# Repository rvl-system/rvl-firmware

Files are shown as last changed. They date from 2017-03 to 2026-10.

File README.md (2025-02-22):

# RVL Firmware

Source code for my RVL system, meant to be run on [RVL Controller Boards](https://github.com/rvl-system/rvl-controller-board). Written using [PlatformIO](http://platformio.org/).

This project is still under heavy development, documentation coming soon once things have settled!

In the mean time, check out this tech demo video of the hardware (as of July 2018).

<a href="https://www.youtube.com/watch?v=nYG6840g4mw" target="_blank">
  Video of a tech demonstration of RVL version 3
</a>

And a photo of the system on my bike at Burning Man 2017:

Photo of RVL on a bike at Burning Man 2017

And finally a video of an art piece I designed the lighting for at Burning Man 2019

<a href="https://www.youtube.com/watch?v=HZNM6n1g5n8" target="_blank">
  Video of a tech demonstration of RVL version 3
</a>

## Notes

The ESP32 sometimes has trouble with Linksys brand routers. If you find that controllers work for a while, then disconnect and never reconnect, try a different router.

# License

All schematics, layouts, software, and other documentation for raver-lights is released under the General Public License.

Copyright (c) Bryan Hughes <bryan@nebri.us>

RVL is free software: you can redistribute it and/or modify
it under the terms of the GNU General Public License as published by
the Free Software Foundation, either version 3 of the License, or
(at your option) any later version.

RVL is distributed in the hope that it will be useful,
but WITHOUT ANY WARRANTY; without even the implied warranty of
MERCHANTABILITY or FITNESS FOR A PARTICULAR PURPOSE.  See the
GNU General Public License for more details.

You should have received a copy of the GNU General Public License
along with RVL.  If not, see <http://www.gnu.org/licenses/>.

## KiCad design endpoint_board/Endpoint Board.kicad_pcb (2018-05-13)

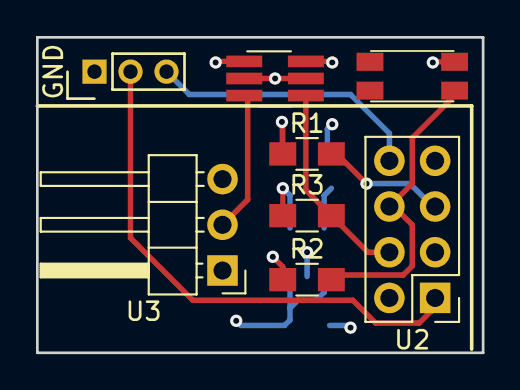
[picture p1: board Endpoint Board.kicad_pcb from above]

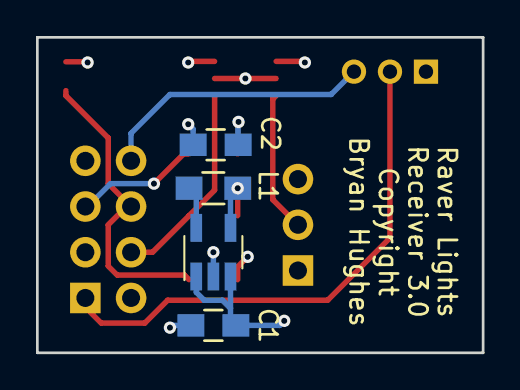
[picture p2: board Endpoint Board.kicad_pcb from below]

Board: 4 copper layers, 24.8 x 17.5 mm, 12 parts (4 on the bottom side), 10 nets.

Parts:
C1: 4.7uF; C_0805_HandSoldering
C2: 10uF; C_0805_HandSoldering
L1: 2.2uH; R_0805_HandSoldering
P4: SERIAL; Pin_Header_Straight_1x03_Pitch2.00mm
R1, R3: 10k; R_0805_HandSoldering
R2: 1k; R_0805_HandSoldering
SW1: SW_DPST; KMR641NG
U1: LM3671; SOT-23-5_HandSoldering
U2: ESP-01; Pin_Header_Straight_2x04_Pitch2.54mm
U3: NeoPixel; Pin_Header_Angled_1x03_Pitch2.54mm
U4: SN74LVC1T45; TSOT-23-6_HandSoldering

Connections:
+5V: C1.1, U1.1, U1.3, U3.3, U4.1
GND: C1.2, C2.2, P4.1, SW1.2, U1.2, U2.2, U3.1, U4.2, U4.5
unnamed: L1.1, U1.5
unnamed: P4.2, U2.1
unnamed: P4.3, U2.8
unnamed: R1.2, U2.5
unnamed: R2.2, SW1.1, U2.6
unnamed: R3.2, U2.4, U4.4
unnamed: U3.2, U4.3
VCC: C2.1, L1.2, R1.1, R2.1, R3.1, U1.4, U2.3, U2.7, U4.6

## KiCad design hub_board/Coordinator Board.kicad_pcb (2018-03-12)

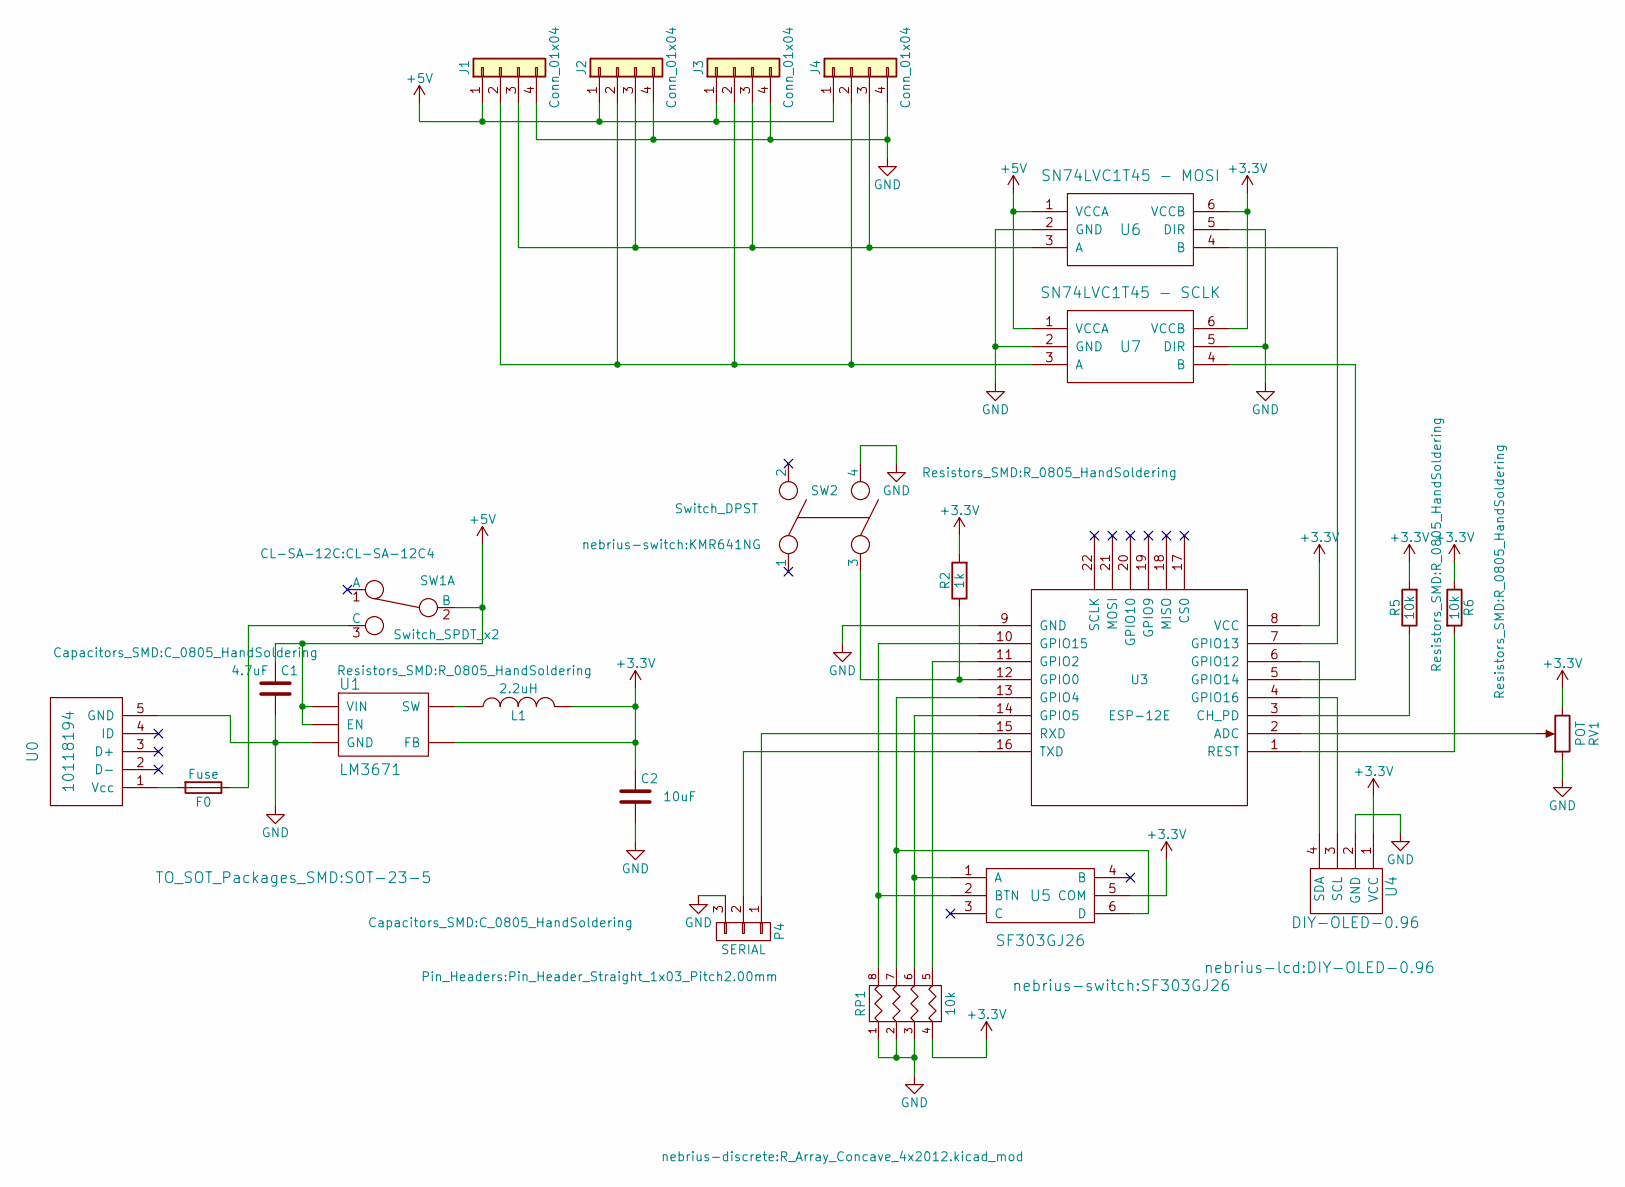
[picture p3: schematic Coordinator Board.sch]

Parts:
C1: 4.7uF; C_0805_HandSoldering
C2: 10uF; C_0805_HandSoldering
F0: Fuse; R_0805_HandSoldering
J1, J2, J3, J4: Conn_01x04; Pin_Header_Angled_1x04_Pitch2.54mm
L1: 2.2uH; R_0805_HandSoldering
P4: SERIAL; Pin_Header_Straight_1x03_Pitch2.00mm
R2: 1k; R_0805_HandSoldering
R5, R6: 10k; R_0805_HandSoldering
RP1: 10k; R_Array_Concave_4x2012.kicad_mod
RV1: POT; Model-35-Pot
SW1: Switch_SPDT_x2; CL-SA-12C4
SW2: Switch_DPST; KMR641NG
U0: 10118194
U1: LM3671; SOT-23-5
U3: ESP-12E; ESP-12E_SMD
U4: DIY-OLED-0.96
U5: SF303GJ26
U6: SN74LVC1T45 - MOSI; SOT-23-6_Handsoldering
U7: SN74LVC1T45 - SCLK; SOT-23-6_Handsoldering

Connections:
+3V3: C2.1, L1.2, R2.2, R5.2, R6.1, RP1.4, RV1.3, U1.4 (FB), U3.8 (VCC), U4.1 (VCC), U5.5 (COM), U6.6 (VCCB), U7.6 (VCCB)
+5V: C1.1, J1.1, J2.1, J3.1, J4.1, SW1.2 (B), U1.1 (VIN), U1.3 (EN), U6.1 (VCCA), U7.1 (VCCA)
GND: C1.2, C2.2, J1.4, J2.4, J3.4, J4.4, P4.3, RP1.1, RP1.2, RP1.3, RV1.1, SW2.4, U0.5 (GND), U1.2 (GND), U3.9 (GND), U4.2 (GND), U6.2 (GND), U6.5 (DIR), U7.2 (GND), U7.5 (DIR)
unnamed: F0.1, SW1.3 (C)
unnamed: F0.2, U0.1 (Vcc)
unnamed: J1.2, J2.2, J3.2, J4.2, U7.3 (A)
unnamed: J1.3, J2.3, J3.3, J4.3, U6.3 (A)
unnamed: L1.1, U1.5 (SW)
unnamed: P4.1, U3.15 (RXD)
unnamed: P4.2, U3.16 (TXD)
unnamed: R2.1, SW2.3, U3.12 (GPIO0)
unnamed: R5.1, U3.3 (CH_PD)
unnamed: R6.2, U3.1 (REST)
unnamed: RP1.5 (R4), U3.11 (GPIO2)
unnamed: RP1.6 (R3), U3.14 (GPIO5), U5.1 (A)
unnamed: RP1.7 (R2), U3.13 (GPIO4), U5.6 (D)
unnamed: RP1.8 (R1), U3.10 (GPIO15), U5.2 (BTN)
unnamed: RV1.2, U3.2 (ADC)
unnamed: U3.4 (GPIO16), U4.3 (SCL)
unnamed: U3.5 (GPIO14), U7.4 (B)
unnamed: U3.6 (GPIO12), U4.4 (SDA)
unnamed: U3.7 (GPIO13), U6.4 (B)

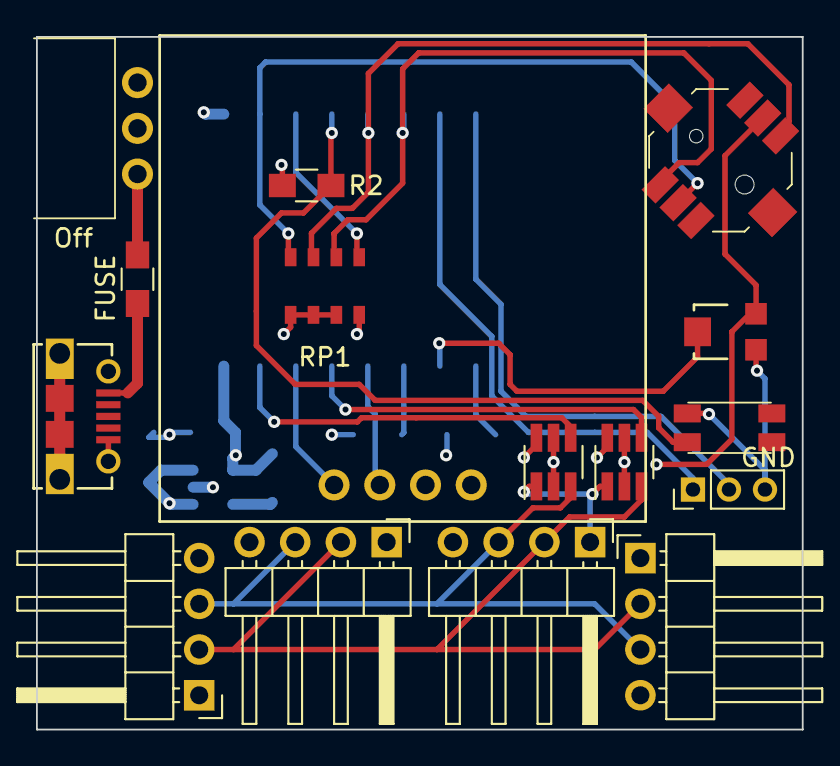
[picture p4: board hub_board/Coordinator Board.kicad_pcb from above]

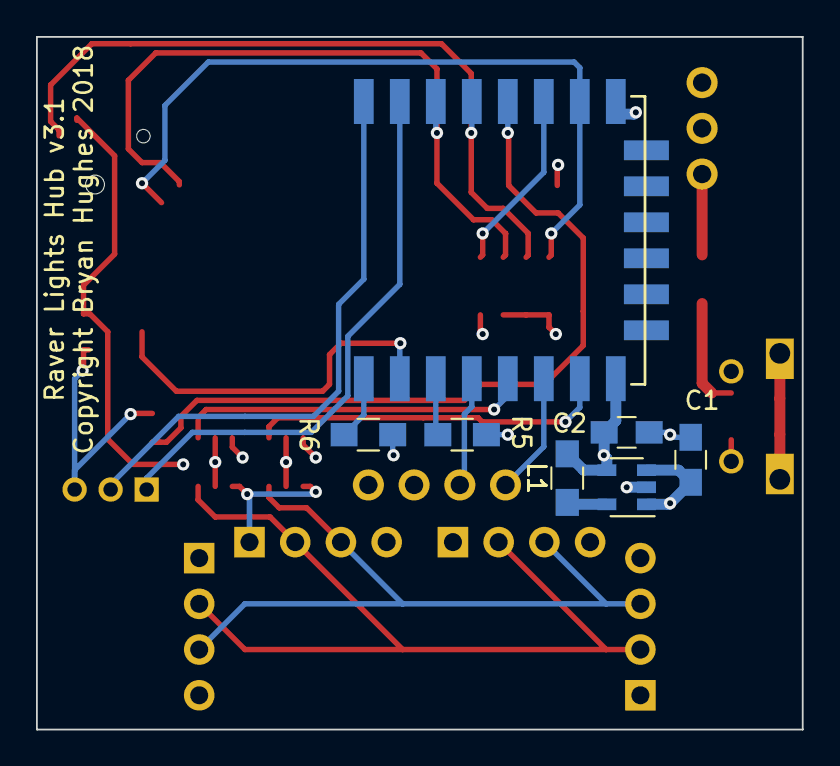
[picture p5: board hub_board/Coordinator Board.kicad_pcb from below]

Board: 4 copper layers, 42.5 x 38.5 mm, 23 parts (7 on the bottom side), 22 nets.

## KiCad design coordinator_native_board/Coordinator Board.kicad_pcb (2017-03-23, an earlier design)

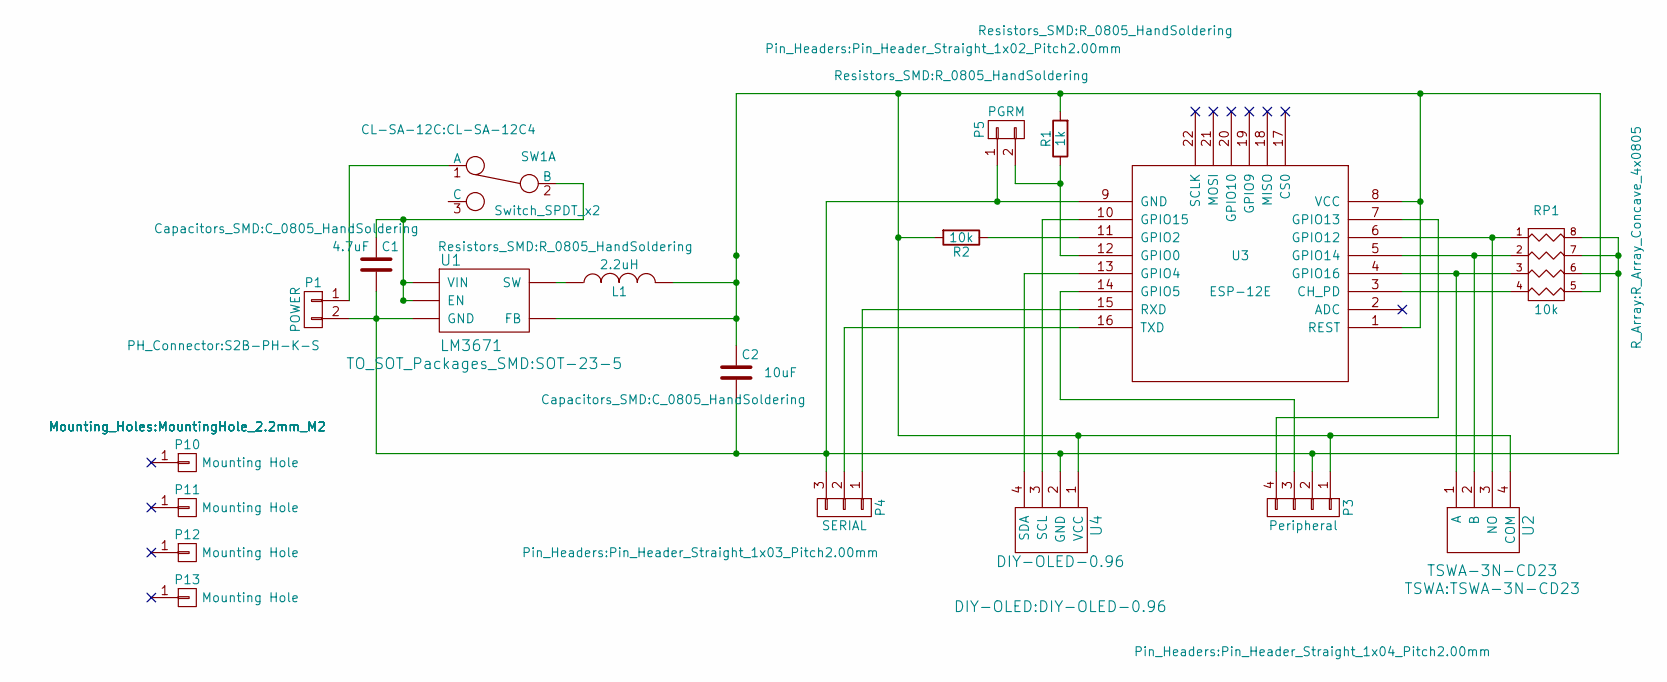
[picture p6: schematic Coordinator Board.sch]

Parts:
C1: 4.7uF; C_0805_HandSoldering
C2: 10uF; C_0805_HandSoldering
L1: 2.2uH; R_0805_HandSoldering
P1: POWER; S2B-PH-K-S
P3: Peripheral; Pin_Header_Straight_1x04_Pitch2.00mm
P4: SERIAL; Pin_Header_Straight_1x03_Pitch2.00mm
P5: PGRM; Pin_Header_Straight_1x02_Pitch2.00mm
P10, P11, P12, P13: Mounting Hole; MountingHole_2.2mm_M2
R1: 1k; R_0805_HandSoldering
R2: 10k; R_0805_HandSoldering
RP1: 10k; R_Array_Concave_4x0805
SW1: Switch_SPDT_x2; CL-SA-12C4
U1: LM3671; SOT-23-5
U2: TSWA-3N-CD23
U3: ESP-12E; ESP-12
U4: DIY-OLED-0.96

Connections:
unnamed: C1.1, SW1.2 (B), U1.1 (VIN), U1.3 (EN)
unnamed: C1.2, C2.2, P1.2, P3.2, P4.3, P5.1, RP1.6 (R3), RP1.7 (R2), RP1.8 (R1), U1.2 (GND), U3.9 (GND), U4.2 (GND)
unnamed: C2.1, L1.2, P3.1, R1.2, R2.2, RP1.5 (R4), U1.4 (FB), U2.4 (COM), U3.1 (REST), U3.8 (VCC), U4.1 (VCC)
unnamed: L1.1, U1.5 (SW)
unnamed: P1.1, SW1.1 (A)
unnamed: P3.3, U3.14 (GPIO5)
unnamed: P3.4, U3.7 (GPIO13)
unnamed: P4.1, U3.15 (RXD)
unnamed: P4.2, U3.16 (TXD)
unnamed: P5.2, R1.1, U3.12 (GPIO0)
unnamed: R2.1, U3.11 (GPIO2)
unnamed: RP1.1, U2.3 (NO), U3.6 (GPIO12)
unnamed: RP1.2, U2.2 (B), U3.5 (GPIO14)
unnamed: RP1.3, U2.1 (A), U3.4 (GPIO16)
unnamed: RP1.4, U3.3 (CH_PD)
unnamed: U3.10 (GPIO15), U4.3 (SCL)
unnamed: U3.13 (GPIO4), U4.4 (SDA)

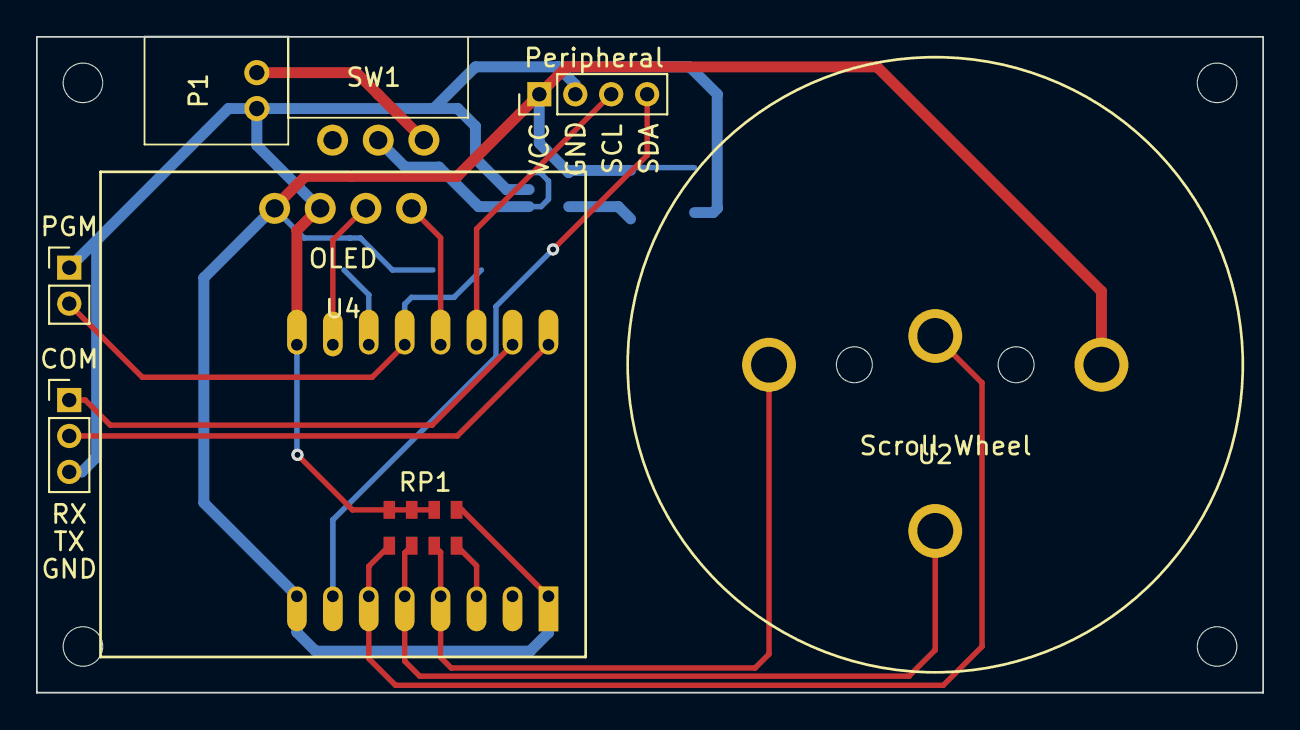
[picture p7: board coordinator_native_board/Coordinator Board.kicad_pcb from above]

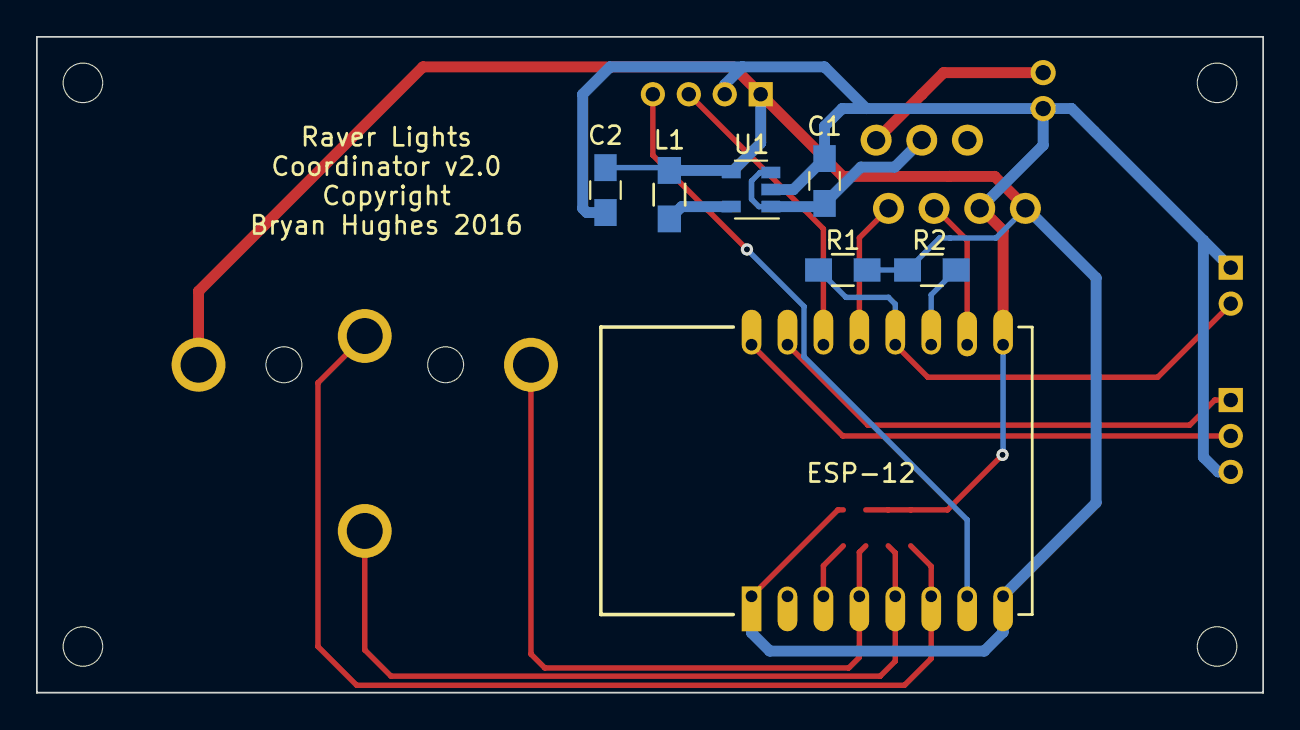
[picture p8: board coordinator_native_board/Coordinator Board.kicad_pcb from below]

Board: 2 copper layers, 68.2 x 36.5 mm, 19 parts (7 on the bottom side), 17 nets.

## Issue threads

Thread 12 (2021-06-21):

Wifi disconnects after some time

nebrius, 2021-06-21:

nebrius, 2021-07-05:
Turns out some [Linksys routers don't like the ESP32](https://github.com/me-no-dev/ESPAsyncWebServer/issues/437), and doesn't seem to be anything I can do about it after a lot of experimentation,.

Closed 2021-07-05.

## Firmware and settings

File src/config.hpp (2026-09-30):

/*
Copyright (c) Bryan Hughes <bryan@nebri.us>

This file is part of RVL Firmware.

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
You should have received a copy of the GNU General Public License
along with RVL Firmware.  If not, see <http://www.gnu.org/licenses/>.
*/

#include <stdint.h>
#include <vector>

#ifndef CONFIG_H_
#define CONFIG_H_

struct StripSegment {
  uint16_t start;
  uint16_t end;
  uint8_t offset;
  bool reverse;
};

/**** You'll probably want to modify these settings ****/

#define LED_COLOR_MODE GRB
#define LED_NUM_PIXELS 300

#define SCREEN_SAVER_ENABLED

extern std::vector<StripSegment> segments;

/**** You *may* want to modify these settings, but it's not likely ****/

#define SERIAL_BAUDRATE 115200

#define DEFAULT_CHANNEL 0
#define DEFAULT_PRESET 2
#define DEFAULT_BRIGHTNESS 50
#define MIN_BRIGHTNESS 25
#define MAX_BRIGHTNESS 200

#define SCREEN_OFF_TIME 10000

#define CONNECTING_PIXEL_PERIOD 2000

/**** You most likely should *not* modify these settings ****/

#define BUTTON_PRESS_ENGAGE_TIME 50
#define BUTTON_HOLD_ENGAGE_TIME 2000

#ifdef RVL_CONTROLLER
#include "./config-controller.hpp"
#endif
#ifdef RVL_RECEIVER
#include "./config-receiver.hpp"
#endif
#ifdef RVL_ESP8266
#include "./config-esp8266.hpp"
#endif

#endif // CONFIG_H_

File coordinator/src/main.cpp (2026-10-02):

/*
Copyright (c) Bryan Hughes <bryan@nebri.us>

This file is part of RVL Firmware.

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
You should have received a copy of the GNU General Public License
along with RVL Firmware.  If not, see <http://www.gnu.org/licenses/>.
*/

#include <WiFi.h>
#include <WiFiUdp.h>
#include <esp_wifi.h>
#include <rvl/config.hpp>
#include <string.h>

#define WIFI_CHANNEL 3

// A set is NUM_OBSERVATIONS_IN_SET broadcasts spaced REFERENCE_SPACING apart,
// with SET_PERIOD from the start of one set to the start of the next
#define SET_PERIOD 2300
#define REFERENCE_SPACING 100

// The coordinator speaks only RVLI: it answers requests and broadcasts clock
// references on the same socket
WiFiUDP rvliUdp;

uint16_t id = 0;
uint8_t deviceId = 0;

// Reference broadcasts are scheduled rather than delayed so loop() always
// returns promptly. Anything that blocks here stops the coordinator answering
// the requests it also serves
uint32_t setStartTime = 0;
uint32_t nextReferenceTime = 0;
uint8_t referencesSentInSet = NUM_OBSERVATIONS_IN_SET;

void write8(WiFiUDP& udp, uint8_t data) {
  udp.write(data);
}

void write16(WiFiUDP& udp, uint16_t data) {
  udp.write(data >> 8);
  udp.write(data & 0xFF);
}

void write(WiFiUDP& udp, uint8_t* data, uint16_t length) {
  size_t written = udp.write(data, length);
  if (written != length) {
    Serial.println("Error sending buffer");
  }
}

void handleRvliPacket() {
  if (rvliUdp.parsePacket() == 0) {
    return;
  }

  uint8_t header[8];
  int read = rvliUdp.read(header, sizeof(header));
  IPAddress requester = rvliUdp.remoteIP();
  uint16_t requesterPort = rvliUdp.remotePort();

  if (read < static_cast<int>(sizeof(header)) ||
      memcmp(header, rvl::rvliSignature, 4) != 0)
  {
    rvliUdp.clear();
    return;
  }
  if (header[4] != RVLI_VERSION) {
    Serial.printf("Ignoring RVLI version %d\n", header[4]);
    rvliUdp.clear();
    return;
  }

  // header[5] is the source, which the coordinator has no use for
  switch (header[6]) {
  case RVLI_PACKET_TYPE_ID_ASSIGNMENT: {
    uint8_t subType = rvliUdp.read();
    rvliUdp.clear();
    if (subType != ID_REQUEST_TYPE) {
      return; // A reply, which we send rather than receive
    }
    // The requester's own address is what makes the ID unique without an
    // allocator here: the DHCP server already guarantees no two stations share
    // one, and it is the only party that can. That derivation is private to the
    // coordinator, so a future non-IP transport can hand out something else
    uint8_t assignedId = requester[3];
    if (assignedId >= NUM_DEVICE_IDS) {
      // The pool is exhausted, or the AP moved onto a subnet whose addresses
      // can't be device IDs. Say nothing: silence is wire-identical to being
      // down, which the requester already retries against
      Serial.printf("Cannot assign ID %d, out of range\n", assignedId);
      return;
    }
    rvliUdp.beginPacket(requester, requesterPort);
    write(rvliUdp, rvl::rvliSignature, 4);
    write8(rvliUdp, RVLI_VERSION);
    write8(rvliUdp, deviceId);
    write8(rvliUdp, RVLI_PACKET_TYPE_ID_ASSIGNMENT);
    write8(rvliUdp, 0); // Reserved
    write8(rvliUdp, ID_REPLY_TYPE);
    write8(rvliUdp, assignedId);
    rvliUdp.endPacket();
    Serial.printf(
        "Assigned ID %d to %s\n", assignedId, requester.toString().c_str());
    break;
  }
  case RVLI_PACKET_TYPE_CLOCK_SYNC:
    // Boards' observations of our references, which only other boards use
    rvliUdp.clear();
    break;
  default:
    Serial.printf("Ignoring unknown RVLI packet type %d\n", header[6]);
    rvliUdp.clear();
    break;
  }
}

void sendReferenceBroadcast(bool isStartOfSet) {
  IPAddress ip(255, 255, 255, 255);
  rvliUdp.beginPacket(ip, RVLI_PORT);

  write(rvliUdp, rvl::rvliSignature, 4);
  write8(rvliUdp, RVLI_VERSION);
  write8(rvliUdp, deviceId);
  write8(rvliUdp, RVLI_PACKET_TYPE_CLOCK_SYNC);
  write8(rvliUdp, 0); // Reserved

  write8(rvliUdp, 1); // Clock sync subpacket type: reference broadcast
  write16(rvliUdp, id);
  write8(rvliUdp, 0); // Reserved
  write8(rvliUdp, isStartOfSet ? 1 : 0);
  write8(rvliUdp, 0); // Reserved

  rvliUdp.endPacket();
}

void setup() {
  Serial.begin(115200);

  Serial.println("Setting AP (Access Point)...");
  WiFi.softAP(DEFAULT_WIFI_SSID, DEFAULT_WIFI_PASSPHRASE, WIFI_CHANNEL);

  wifi_config_t conf;
  esp_wifi_get_config(WIFI_IF_AP, &conf);
  conf.ap.dtim_period = 1;
  conf.ap.max_connection = 15;
  esp_wifi_set_config(WIFI_IF_AP, &conf);

  IPAddress ip = WiFi.softAPIP();
  Serial.print("AP IP address: ");
  Serial.println(ip);

  // Boards drop any packet whose source is >= 240, so an AP address ending
  // there would silently kill clock sync for the whole fleet.
  //
  // This ID must also never be one a board can be assigned, or that board would
  // drop every reference as its own. That holds because the DHCP server never
  // leases its own address, which is only true while the coordinator is the AP
  deviceId = ip[3];
  if (deviceId >= NUM_DEVICE_IDS) {
    Serial.println("ERROR: AP address ends >= 240, boards will ignore us");
  }

  rvliUdp.begin(RVLI_PORT);
}

void loop() {
  // Always first, and never behind an early return: a board with no ID can't do
  // anything until this is answered, and it retries on a ~1s timer
  handleRvliPacket();

  uint32_t now = millis();
  if (static_cast<int32_t>(now - nextReferenceTime) < 0) {
    return;
  }

  if (referencesSentInSet >= NUM_OBSERVATIONS_IN_SET) {
    // Receivers map each broadcast to an observation slot via
    // id % NUM_OBSERVATIONS_IN_SET, so every broadcast in a set needs its own
    // consecutive id. Reset before the uint16 wrap so a set never spans it,
    // which would map two broadcasts to one slot
    if (id > UINT16_MAX - NUM_OBSERVATIONS_IN_SET) {
      id = 0;
    }
    referencesSentInSet = 0;
    setStartTime = now;
  }

  sendReferenceBroadcast(referencesSentInSet == 0);
  id++;
  referencesSentInSet++;

  // Sets are phase locked to setStartTime rather than chained off the last
  // send, so a late loop iteration doesn't push the whole schedule back
  nextReferenceTime = referencesSentInSet < NUM_OBSERVATIONS_IN_SET
      ? now + REFERENCE_SPACING
      : setStartTime + SET_PERIOD;
}

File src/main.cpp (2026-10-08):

/*
Copyright (c) Bryan Hughes <bryan@nebri.us>

This file is part of RVL Firmware.

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
You should have received a copy of the GNU General Public License
along with RVL Firmware.  If not, see <http://www.gnu.org/licenses/>.
*/

#include <Arduino.h>
#ifdef ESP32
#include <rvl-esp32-wifi.hpp>
#else
#include <rvl-wifi.hpp>
#endif
#include <rvl.hpp>
#include <rvl/config.hpp>

#ifdef HAS_UI
#include "./ui/screen.hpp"
#include "./ui/ui.hpp"
#endif
#ifdef HAS_CONTROLS
#include "./controls/controls.hpp"
#endif
#include "./config.hpp"
#include "./lights.hpp"
#include "./settings.hpp"
#include "./timing_stats.hpp"

TimingStats backgroundStats;
TimingStats foregroundStats;

#ifdef ESP32
RVLESP32Wifi::System* wifiSystem;
#else
RVLWifi::System* wifiSystem;
#endif

void startBackgroundLoop();

void setup() {
  Settings::init();

  Serial.begin(SERIAL_BAUDRATE);
#ifdef LOG_DEBUG_ENABLED
  rvl::setLogLevel(rvl::LogLevel::Debug);
#elif LOG_INFO_ENABLED
  rvl::setLogLevel(rvl::LogLevel::Info);
#else
  rvl::setLogLevel(rvl::LogLevel::Error);
#endif

#ifdef ESP32
  wifiSystem = new RVLESP32Wifi::System(
      Settings::getWiFiSSID(), Settings::getWiFiPassphrase());
#else
  wifiSystem = new RVLWifi::System(
      Settings::getWiFiSSID(), Settings::getWiFiPassphrase());
#endif
  rvl::init(wifiSystem);

  rvl::info("Initializing");
#ifdef ESP32
  rvl::info("Network transport: AsyncUDP (RVLESP32Wifi)");
#else
  rvl::info("Network transport: polling WiFiUDP (RVLWifi)");
#endif

  rvl::info("Device mode: %d", static_cast<int>(rvl::getDeviceMode()));
  rvl::info("Channel: %d", rvl::getChannel());
  rvl::info("Brightness: %d", rvl::getBrightness());

#ifdef HAS_UI
  UI::init();
  Screen::init();
#endif
#ifdef HAS_CONTROLS
  Controls::init();
#endif
  Lights::init();
  startBackgroundLoop();
  rvl::info("Running");
}

// Pacing is the caller's job: the background task paces itself in
// backgroundLoopRunner, while on single-loop platforms the foreground's
// frame-aligned sleep paces both loops together
void backgroundLoop() {
  uint32_t startTime = millis();
#ifdef HAS_UI
  UI::loop();
#endif
#ifdef HAS_CONTROLS
  Controls::loop();
#endif
  Settings::loop();
  rvl::loop();
  backgroundStats.record(millis() - startTime);
  backgroundStats.log("Background loop");
}

// Sleeps to the next frame boundary in animation-clock time, so every node
// renders the same instants, plus a millisecond: delay(n) can return a tick
// short of n ms, and a wake before the boundary would read the old frame
void delayUntilNextFrame() {
  uint32_t clock = rvl::getAnimationClock();
  delay(FRAME_PERIOD - (clock % FRAME_PERIOD) + 1);
}

void backgroundLoopRunner(void* parameters) {
  while (true) {
    backgroundLoop();
    delayUntilNextFrame();
  }
}

// Must run exactly once: the network transport and protocol state driven by the
// background loop are not safe to use from more than one task
void startBackgroundLoop() {
#ifdef ESP32
  // Priority 1: this task polls and sleeps, and must never outrank the WiFi
  // stack (the old 255 was silently clamped to max, starving the WiFi task on
  // this core and delaying packet delivery)
  xTaskCreatePinnedToCore(backgroundLoopRunner, "backgroundLoopRunner", 20192,
      NULL, 1, NULL, xPortGetCoreID() == 0 ? 1 : 0);
#endif
}

// The strip first, so a dissolve's frame goes out right after waking on its
// boundary, and the screen's draw after it
void foregroundLoop() {
  uint32_t startTime = millis();
  Lights::loop();
#ifdef HAS_UI
  Screen::loop();
#endif
  foregroundStats.record(millis() - startTime);
  foregroundStats.log("Foreground loop");
  delayUntilNextFrame();
}

void loop() {
#ifndef ESP32
  backgroundLoop();
#endif
  foregroundLoop();
}

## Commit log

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2016-12-13 Set up footprints for esp dock
    [esp_dock.kicad_pcb, esp_dock.sch]
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2016-12-21 Finished v1.5 of the board
    [esp_dock.kicad_pcb, esp_dock.sch]
2016-12-21 Removed file no longer needed
    [_saved_esp_dock.sch]
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2017-01-11 First stab at coordinator board
    [Coordinator Board.kicad_pcb, Coordinator Board.sch]
2017-01-11 Finished v1 of the board
    [Coordinator Board.kicad_pcb, Coordinator Board.sch]
2017-01-31 Cleaning up a ton of stuff
    [Endpoint Board.kicad_pcb, Endpoint Board.sch, esp_dock.kicad_pcb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]
2017-03-23 Committing *some* version of the native board
    I messed this commit up. I created an earlier version of the board but forgot to commit the results. This includes a few modifications, but isn’t ready for fabrication yet :-/
    [Coordinator Board.kicad_pcb, Coordinator Board.sch]
2017-03-23 Reworked to use a rotary encoder
    [input.cpp, main.cpp]
2017-03-23 Fixed some idling bugs
    [input.cpp]
2017-03-23 Removed early RPi coordinator work
    [Coordinator Board.kicad_pcb, Coordinator Board.sch]
2017-03-23 Reworked coordinator to use a generic rotary encoder
    [Coordinator Board.sch]
2017-03-23 Moved temp native name
    [Coordinator Board.kicad_pcb, Coordinator Board.sch]
2017-03-23 Added rotary encoder to schematic
    [Coordinator Board.sch]
2017-03-24 Added rotary encoder footprint
    [Coordinator Board.kicad_pcb, Coordinator Board.sch]
2017-04-10 Finished revision of coordinator board
    [Coordinator Board.kicad_pcb, Coordinator Board.sch]
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2017-06-30 Created v2.6 of the coordinator board
    [Coordinator Board.kicad_pcb, Coordinator Board.sch]
2017-07-07 Worked in input controls and fixed pulse animations
    [input.cpp]
2017-07-09 v2.7 of the coordinator board
    [Coordinator Board.kicad_pcb, Coordinator Board.sch]
2017-12-30 Removed local components in favor of global submodule
    [Coordinator Board.sch]
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2017-12-31 Fixed ESP footprint
    [Coordinator Board.sch]
2018-01-14 Finalized first draft of new schematic
    [Coordinator Board.sch]
2018-01-14 Created new part layout
    [Coordinator Board.kicad_pcb]
2018-01-15 Finished most of the layout
    [Coordinator Board.kicad_pcb, Coordinator Board.sch]
2018-01-26 Revised schematic and added BOM
    [Coordinator Board.kicad_pcb, Coordinator Board.sch]
2018-01-26 Fixed BOM formatting
2018-01-26 Added some better surge protection
    [Coordinator Board.sch]
2018-01-27 Relaid out parts on board
    [Coordinator Board.kicad_pcb]
2018-01-27 Added power planes and small tweaks
    [Coordinator Board.kicad_pcb, Coordinator Board.sch]
2018-01-27 Finished first draft of the board
    [Coordinator Board.kicad_pcb]
2018-01-28 Board cleanup and DRC fix
    [Coordinator Board.kicad_pcb]
2018-01-28 Tweaked silk screen layout
    [Coordinator Board.kicad_pcb]
2018-01-28 Merged board directory structure
    [Coordinator Board.kicad_pcb, Coordinator Board.sch, Endpoint Board.kicad_pcb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]
2018-02-04 Finished and ordered v3.0 of the board!!
    [Coordinator Board.kicad_pcb, Coordinator Board.sch]
2018-02-20 Updated through first build
    [Coordinator Board.kicad_pcb, Coordinator Board.sch]
2018-02-20 Initial 3.1 board redesign
    [Coordinator Board.kicad_pcb, Coordinator Board.sch]
2018-02-20 Finished v3.1 of the board
    [Coordinator Board.kicad_pcb, Coordinator Board.sch]
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2018-03-12 Updated r array footprint
    [Coordinator Board.kicad_pcb, Coordinator Board.sch]
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2018-03-12 Renamed hub board folder
    [Coordinator Board.kicad_pcb, Coordinator Board.sch]
2018-03-12 Renamed files and cleaned up library links
    [Hub Board.kicad_pcb, Hub Board.sch]
2018-03-12 Forgot to add unsaved changes
    [Hub Board.sch]
2018-03-20 Restored the endpoint board project
    [Endpoint Board.kicad_pcb, Endpoint Board.sch]
2018-03-20 Cleaned up endpoint board to use newer submodule pattern
    [Endpoint Board.sch]
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2018-03-20 Updated and reverted a whole bunch of changes to use more tried-and-true connections
    [Hub Board.sch]
2018-03-20 Finished redesign, third times the charm?
    [Hub Board.kicad_pcb]
2018-03-20 Forgot to bump the version number on the silkscreen
    [Hub Board.kicad_pcb]
2018-03-20 Removed extra silkscreen text
    [Hub Board.kicad_pcb]
2018-04-15 First steps in merging the endpoint and hub code
    [Hub Board.sch]
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2018-05-07 Fixed bugs, client now works
    [main.cpp, messaging_client.cpp]
2018-05-07 Broke out the client into folder structure like server
    [messaging_client.cpp]
2018-05-08 (Re)Added the RPi expansion board
    [Base Station Board.kicad_pcb, Base Station Board.sch]
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2018-05-12 Switched to using NeoPixels and other board cleanup
    [Hub Board.sch]
2018-05-12 Tweaked interfaces to fix linting errors
    [giggle_pixel.cpp]
2018-05-12 Figured out trick to fixing blinking LEDs (it was interrupts)
2018-05-12 Finished redesigning for WS2812B LEDs
    [Hub Board.kicad_pcb]
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2018-05-13 First draft of the new receivers
    [Endpoint Board.kicad_pcb, Endpoint Board.sch]
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2018-05-14 Added BOM and fuse
    [Receiver Board.kicad_pcb, Receiver Board.sch]
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2018-05-16 Cleaned up code to fix linting errors and other stuff
    [giggle_pixel.cpp, main.cpp]
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2018-05-16 Reworked input->screen flow and found the root cause of the freezing bug
    [input.cpp, main.cpp]
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2018-05-20 Fleshed out some UI layout issues
    [input.cpp]
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2018-12-28 Created powered receiver board
    [Powered Receiver Board.kicad_pcb, Powered Receiver Board.sch]
2019-01-07 Updated project to new KiCAD format
    [Powered Receiver Board-2019-01-06-16-32-28.sch, Powered Receiver Board.kicad_pcb]
2019-02-27 Final version of the powered receiver board
    [Powered Receiver Board.kicad_pcb, Powered Receiver Board.sch]
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2019-04-23 Created configurable receiver board project
    [Configurable Receiver-2019-04-22-22-17-34.sch, Configurable Receiver.kicad_pcb, Configurable Receiver.sch]
2019-06-06 Restructured and upgraded this repo
    [Base Station Board.kicad_pcb, Base Station Board.sch, Configurable Receiver Board-2019-04-22-22-22-11.sch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]
2019-06-06 More work migrating things to the new version of Kicad
    [Configurable Receiver Board.sch, Hub Board-2019-06-05-17-46-29.sch, Hub Board.kicad_pcb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]
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2019-07-16 Started designing next version of the receiver boards
    [Configurable Receiver Board.sch]
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2019-12-23 Added support for ESP32 based boards, w/ new flash script
    [c232hm.cfg, esp-wroom-32.cfg]
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2026-09-14 Fixed packet read errors
    [config-controller.hpp, main.cpp]
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

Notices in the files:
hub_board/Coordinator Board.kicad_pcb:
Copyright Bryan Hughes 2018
